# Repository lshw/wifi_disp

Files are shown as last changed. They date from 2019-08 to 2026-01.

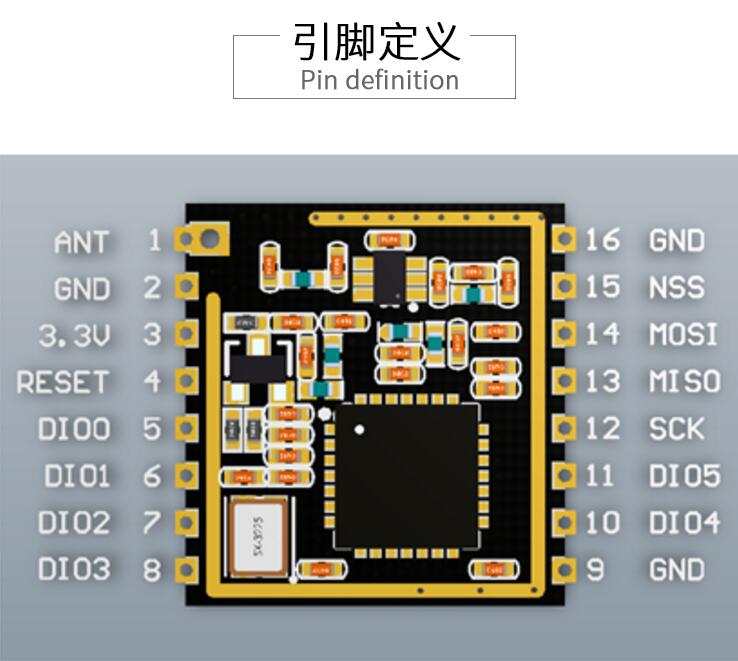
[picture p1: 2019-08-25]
doc/ra-01.jpg

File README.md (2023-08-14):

# wifi_disp
基于arduino开发环境，硬件使用esp8266做的一个智能硬件，可以arduino用串口更新程序，或者arduino用wifi ota方式更新程序

内带锂电池， 充满电， 可以工作40天

可以用wifi从web服务器获取5个数字，显示在数码管显示屏上，

带了个AP功能，让笔记本和手机可以接上来用内带的web服务器进行初始设置。

在连上外网后，还能进行自动远程http升级固件。  
本身带一个温度探头， 精度0.5度， 数据可以传到远程http服务器上进行存储。  
我现在用它给家里的室温和室外温度进行测试并记录，还用它作为美元汇率显示器。  
这个项目也可以作为esp8266开发的一个入门例子。  
源码在wifi_disp目录下。   
编译好的bin在 https://www.anheng.com.cn/wifi_disp.bin  

lib目录下的脚本，是linux下，不用arduino集成环境， 直接用命令行进行编译或者ota或者线刷的脚本

lora_mini是一个兼容arduino的uno，带lora功能的一个小板子，可以作为lora的探头端  

 V2版硬件,增加lora模块，cfido2019同款, 可以作为lora开发板学习研究lora， 也可以作为lora网关， 让lora网络覆盖一个住宅小区。  目前稳定测试通讯距离可以1.3公里  

这里是taobao链接， 提供全套散件，这个小小的套件， 可以体验学习如下诸多内容: 嵌入式开发，wifi开发, arduino,http开发，制作ap接入点，物联网应用，3D打印外壳，基于单片机dns泛域名解析， mdns发现，基于单片机的web服务器，好多内容， 适合于大中小学生玩耍,随便从以上各点取一个方向，做毕业设计是很好的。 

相关的项目链接:  
微信小程序[惠多气象]:https://github.com/scfido/weather_thermometer  
手机APP:https://github.com/liuxiaoyang98/wifi_disp_app  
 
淘宝连接:https://item.taobao.com/item.htm?id=601842691823  

看看能打到第几关:  

第一关，可以拿它当个温度计，可以Web看历史温度，~~小程序看温度~~

~~第二级，可以自动开通ddns.cfido.com,自己玩一些ddns的东西。~~

第三级，可以自己开发Web服务端，让它周期显示一些自己感兴趣的内容,5位数字,比如汇率等

第四级，扩展的TTL串口和I2C，可以自己扩展一些外设

第五级，进行lora无线通讯开发，使用arduino开发环境
模块支持3种通讯模式，2种传统的，和lora模式，频率433-470MHz（433,470是开放频率，可以进行智能家居，物联网等非连续通讯)

第六级，我们要建立开放的基于lora的，低功耗的,低速物联网通讯协议，用无中心的p2p网络实现互联。

编译方法：  
先安装arduino开发环境， 然后增加esp8266支持, 具体就是开发环境下点设置， 增加开发板管理器的url:https://arduino.esp8266.com/stable/package_esp8266com_index.json   
然后在开发板管理器里就可以搜到并安装esp8266的支持了，目前的源码需要选择3.0.2的esp8266支持环境  
在开发板里选Generic ESP8266 Modules 
Flash Size 选4M (fs:2M, 程序1M) 
MMU选16KB cache 48KB IRAM  
就可以编译了。

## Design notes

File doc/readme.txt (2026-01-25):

背后的按键可以切换运行模式
1.测温上传 -> 2.setup设置 -> off 关机

设置温度计wifi上网的方法:

如果wifi有wps快速配网功能，按一下无线AP的WPS键，
然后插上usb线，切换到setup模式,就会自动进行WPS配网，
如果WPS配网没有成功，进入smartconfig模式。 温度计显示 CO xx, 
此时手机连上家里2.4G的wifi网络， 用微信浏览网址
http://wx.ai-thinker.com/api/old/wifi/config
就可以给附近的温度计配置wifi上网密码。配置完成后，温度计会自动重启。
如果上述方法没有成功， 那么可以试试用温度计的AP服务，
在setup模式下, 温度计会生成一个空密码的名字叫disp的wifi接入点AP, 用手机或者笔记本可以搜到它
用手机(先关掉4G)或电脑，连上无线接入点disp后，用浏览器浏览网页http://192.168.4.1，
会打开web设置界面，把家里的WiFi和密码设置进去，然后保存重启。

远程显示温度方式:
温度历史数据地址1:https://temp2.wf163.com:1443/disp
温度历史数据地址2:https://temp.cfido.com/disp

Q&A:

Q:如何升级
A:web界面在线升级， 上传wifi_disp.bin, 或者用串口， 用update.sh在linux下进行升级，windows下需要安装python参考update.sh 用cmd命令行进行升级

Q:为啥会显示[ 3.xx ]或者[ 4.xx ]，并闪动?
A:这是温度计没有连上网络，它会显示电池电压, 需要给温度计配上wifi，让它上网。

Q:为啥温度计显示[OFF3.x]?
A:电池电压过低， 3.x是电池电压, 插上usb线充电就可以了。

Q:为啥显示温度会偏高?
A:在配置wifi时， 可能会因为温度计持续工作， 而造成温度升高， 等1小时后，它下次自动测量数据，就可以显示准确的气温，误差0.5度

Q:还有更详细的说明吗?
A:看源码网站:https:/github.com/lshw/wifi_disp

Q:怎么可以知道设备的序列号?
A:温度计上会有贴纸，写着序列号,如果找不到贴纸， 可以用以下方法， 找到序列号:
A:配好温度计的wifi设置后， 按背后的按键， 让它进入OTA模式, 等它完成上网， 就会在屏幕显示ip地址， 用手机或者电脑浏览这个ip地址，
   出来的设置页面上，可以显示温度计序列号

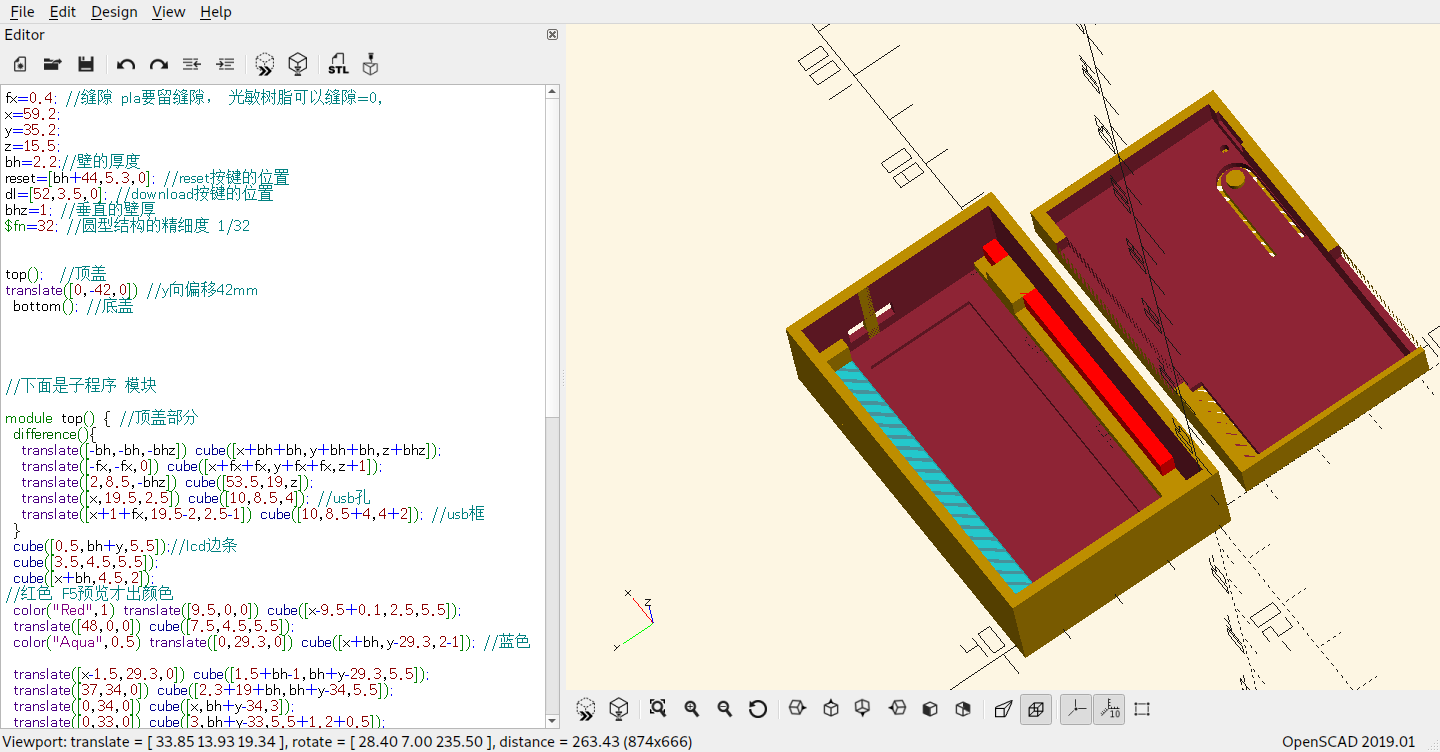
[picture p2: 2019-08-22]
doc/3d.png

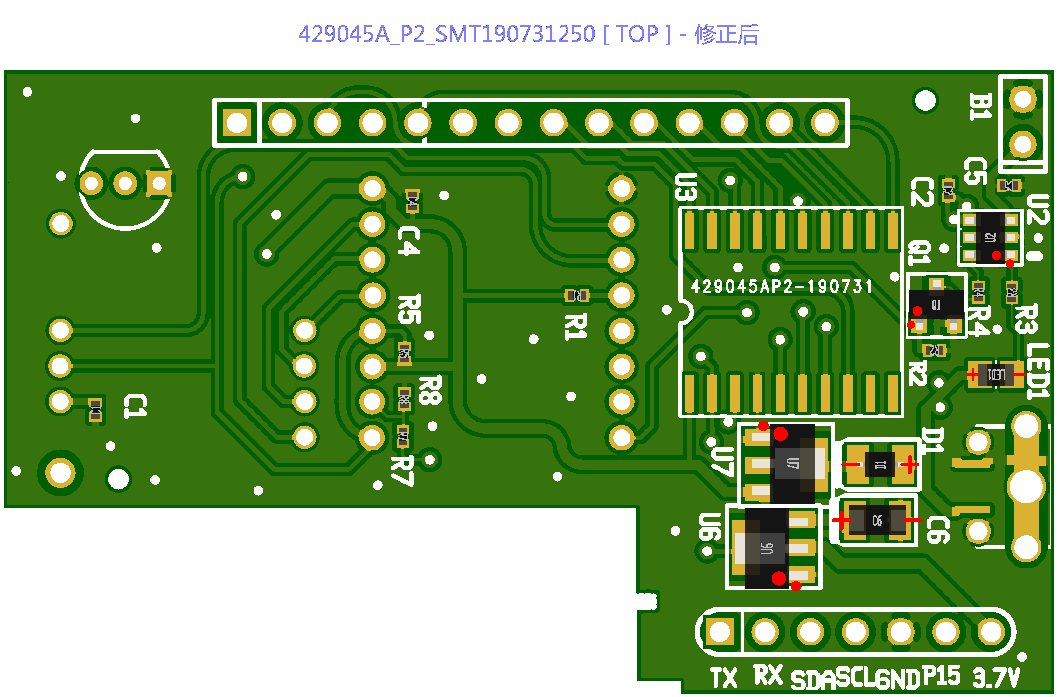
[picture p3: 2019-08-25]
doc/pcb_top.png

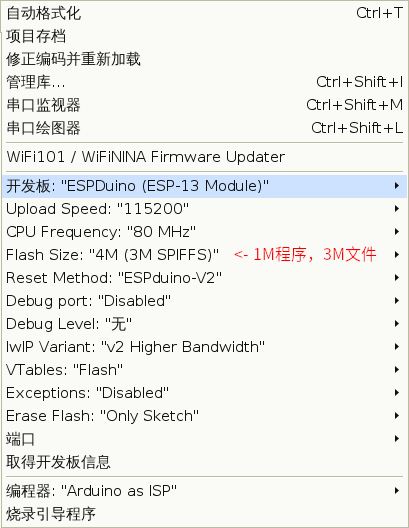
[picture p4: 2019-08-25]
doc/arduino_set.png

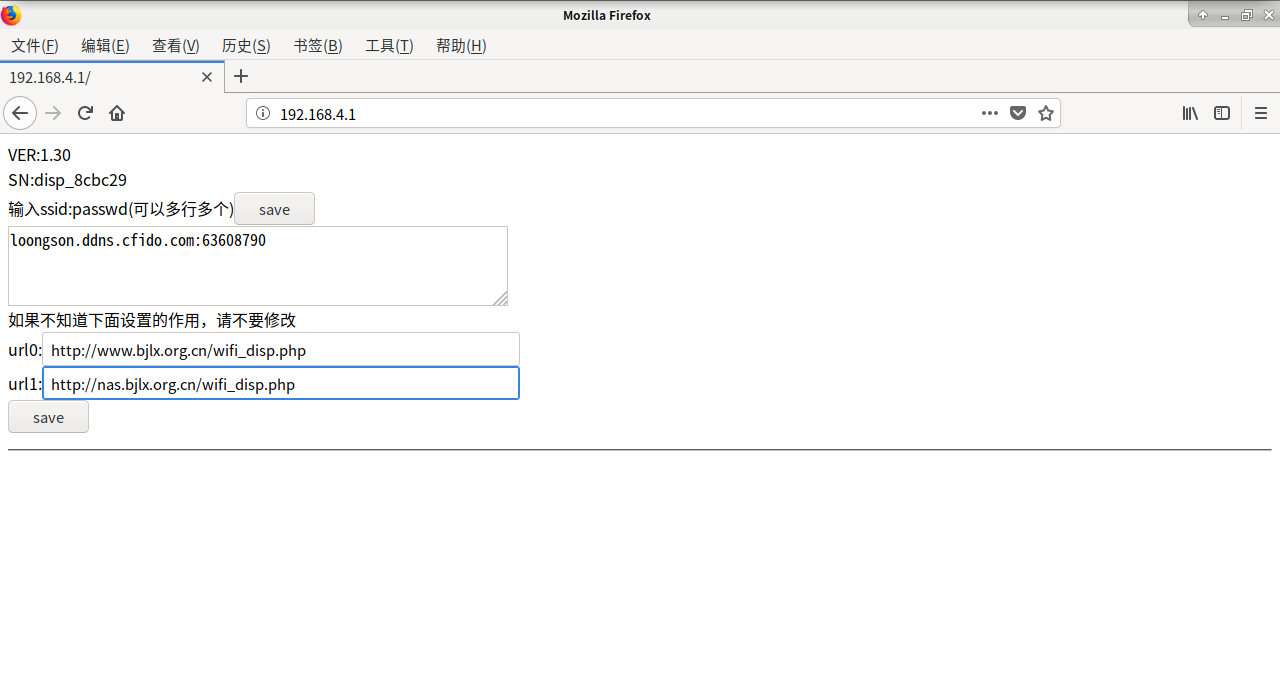
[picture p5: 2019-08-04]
doc/ap.png

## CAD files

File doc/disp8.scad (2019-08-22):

fx=0.4; //缝隙 pla要留缝隙， 光敏树脂可以缝隙=0,
x=59.2;
y=35.2;
z=15.5;
bh=2.2;//壁的厚度
reset=[bh+44,5.3,0]; //reset按键的位置
dl=[52,3.5,0]; //download按键的位置
bhz=1; //垂直的壁厚
$fn=32; //圆型结构的精细度 1/32


top();  //顶盖 
translate([0,-42,0]) //y向偏移42mm 
 bottom(); //底盖




//下面是子程序 模块

module top() { //顶盖部分 
 difference(){
  translate([-bh,-bh,-bhz]) cube([x+bh+bh,y+bh+bh,z+bhz]);
  translate([-fx,-fx,0]) cube([x+fx+fx,y+fx+fx,z]);
  translate([2,8.5,-bhz]) cube([53.5,19,z]);
  translate([x,19.5,2.5]) cube([10,8.5,4]); //usb孔
  translate([x+1+fx,19.5-2,2.5-1]) cube([10,8.5+4,4+2]); //usb框
 }
 cube([0.5,bh+y,5.5]);//lcd边条
 cube([3.5,4.5,5.5]);
 cube([x+bh,4.5,2]);
 translate([9.5,0,0]) cube([x-9.5+0.1,2.5,5.5]);
 translate([48,0,0]) cube([7.5,4.5,5.5]);
 translate([0,29.3,0])
 cube([x+bh,y-29.3,2-1]);

 translate([x-1.5,29.3,0]) cube([1.5+bh-1,bh+y-29.3,5.5]);
 translate([37,34,0]) cube([2.3+19+bh,bh+y-34,5.5]);
 translate([0,34,0]) cube([x,bh+y-34,3]);
 translate([0,33,0]) cube([3,bh+y-33,5.5+1.2+0.5]);
  translate([x+fx,19.5+8.5/2-1,0]) cube([1,2,z]); //usb支撑
}

module switch(){  //按钮开关结构
 fx1=0.8;
 bh=2;
 if(fx>0) { //fx>0 是pla打印，按键的缝隙要宽一点
  fx1=1.6;
 }
 r1=4.8+fx1+fx1;
 difference(){
  union(){
   cylinder(r=r1/2,h=bh);
   translate([-15,-r1/2,0]) cube([15,r1,bh]);
  }//union
  cylinder(r=r1/2-fx1,h=bh);
  translate([-15,-r1/2+fx1,0]) cube([15,r1-fx1-fx1,bh]);
 }//diff
}

module bottom(){ //底盖部分
 z1=5+1.5; //厚度
 bh=2;      //壁厚
 difference(){
  cube([x,y,z1]);
  translate([1,bh,1.5]) cube([x-1-1.6,y-bh-bh,z1]);
  translate([2,30,0]) cube([18,3.1,z1]); //com1
  translate([1,0,z1-3.7]) cube([23,bh,z1]);//电池
  translate([1+18,y-bh,1.5+2]) cube([33,bh,z1]);//天线
  translate(dl) {
   cylinder(r=0.7,h=bh);
   translate([-7/2,-4/2,z1-3]) cube([7,4,z1]); //3x6 开关
  }
  translate(reset) switch();
 }
 translate(reset) cylinder(r=3/2,h=z1-4.2);//按键中心柱
}

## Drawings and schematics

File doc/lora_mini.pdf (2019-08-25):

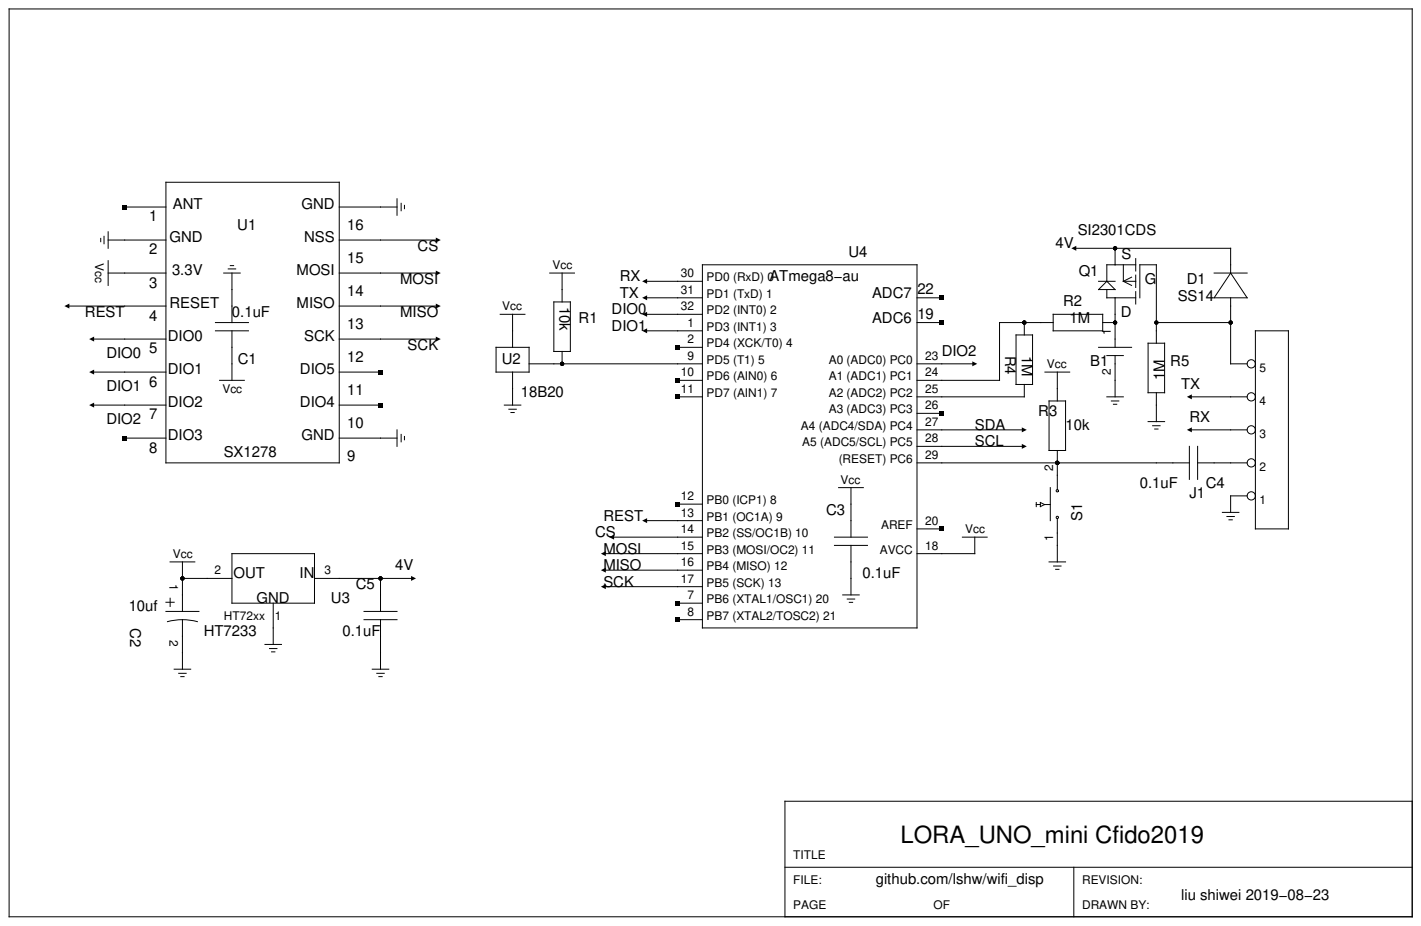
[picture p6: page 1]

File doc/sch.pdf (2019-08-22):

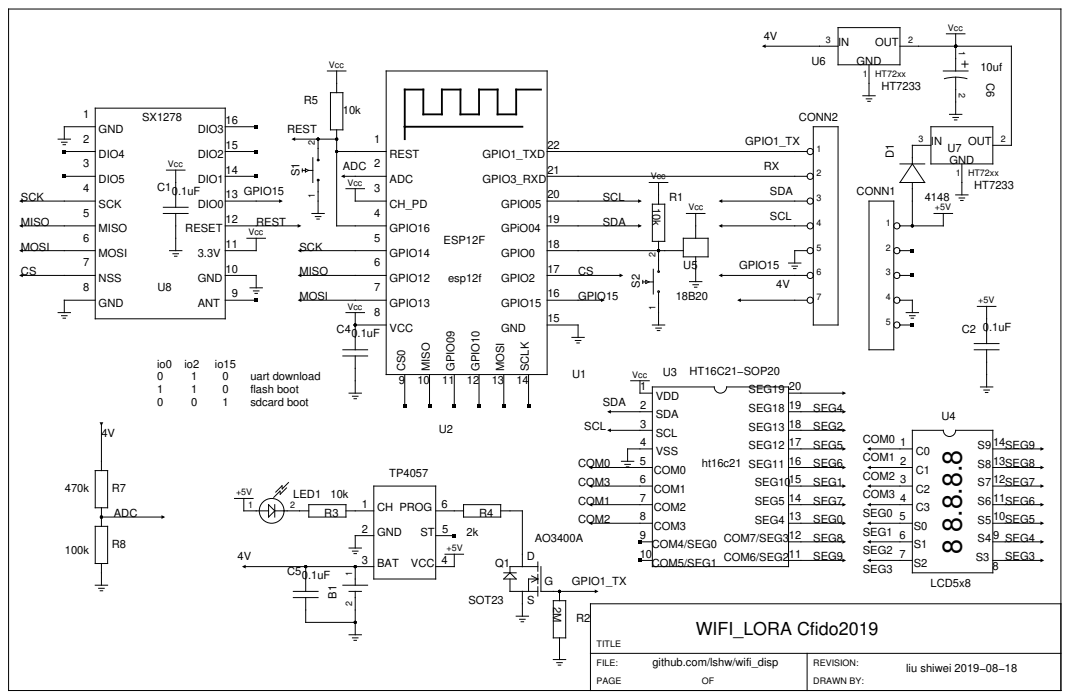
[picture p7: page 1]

liu shiwei 2019−08−18 github.com/lshw/wifi_disp

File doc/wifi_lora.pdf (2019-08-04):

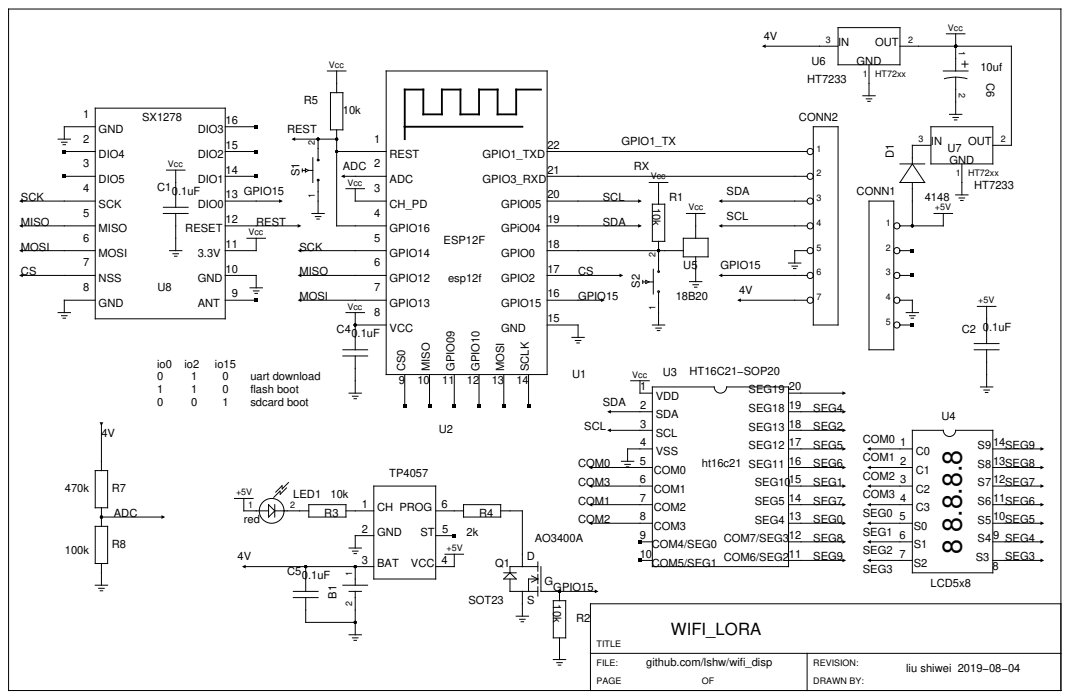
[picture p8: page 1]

liu shiwei 2019−08−04 github.com/lshw/wifi_disp

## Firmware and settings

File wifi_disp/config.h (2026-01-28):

#ifndef _CONFIG_H_
#define _CONFIG_H_

#define VER "1.86"
#define HOSTNAME "disp_"
#define CRC_MAGIC 3
/* ESP32_C3 MAGIC 4 */
#define DEFAULT_URL0 "http://temp.cfido.com:808/wifi_disp.php"
#define DEFAULT_URL1 "http://temp2.wf163.com:808/wifi_disp.php"

#ifndef GIT_VER
#define GIT_VER "test"
#endif
#define DOWNLOAD_KEY 0
#ifndef BUILD_SET
#define BUILD_SET "default"
#endif

#endif  //_CONFIG_H_

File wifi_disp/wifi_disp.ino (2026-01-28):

#include <FS.h>
#ifndef CONFIG_IDF_TARGET_ESP32C3
extern "C" {
#include "user_interface.h"
}
#endif
#include "config.h"
#include "global.h"
void ht16c21_cmd(uint8_t cmd, uint8_t dat);
void init1();
uint32_t next_disp = 1800;  //下次开机
String hostname = HOSTNAME;

#include "ota.h"
#include "ds1820.h"
#include "wifi_client.h"
#include "httpd.h"
#include "ht16c21.h"
#include "lora.h"
#include "dht22.h"
#include "sht4x.h"
#include "setup.h"
#include "proc3.h"
#if __has_include("proc4.h")
#include "proc4.h"
#endif
#if __has_include("proc5.h")
#include "proc5.h"
#endif
bool power_in = false;
void init1() {
  ht16c21_setup();       //180ms
  ht16c21_cmd(0x88, 1);  //闪烁2hz
}
void setup() {
  Serial_begin();
  load_nvram();  //从esp8266的nvram载入数据
  nvram.boot_count++;
  nvram.change = 1;
  if (millis() > 5000) {  //升级程序后第一次启动
    Serial.println(F("升级完成，重启"));
    nvram.charge = 1;
    nvram.change = 1;
    save_nvram();
    poweroff(2);
  }
  //WiFi.setAutoConnect(true);                        //自动链接上次
  if (nvram.have_dht == 0 && nvram.pcb_ver >= 0) {  //dht与wifi_station_connect冲突
    if (nvram.proc == PROC3_MODE || nvram.proc == GENERAL_MODE) {
      wifi_set_opmode(STATION_MODE);
      wifi_set_sleep_type(NONE_SLEEP_T);
      if (!ip_addr_isany(&nvram.ip.ip) && !ip_addr_isany(&nvram.ip.gw) && !ip_addr_isany(&nvram.ip.netmask)) {
        wifi_station_dhcpc_stop();
        wifi_set_ip_info(STATION_IF, &nvram.ip);
        dns_setserver(0, &nvram.dns0);
        dns_setserver(1, &nvram.dns1);
      }
      struct station_config conf = { 0 };
      wifi_station_get_config(&conf);
      conf.channel = nvram.ch;
      wifi_station_set_config_current(&conf);
      wifi_station_connect();
    } else if (nvram.proc == SETUP_MODE) {
      wifi_set_opmode(STATIONAP_MODE);
      wifi_station_connect();
    }
  } else {
    pcb_ver_detect();
  }
  if (nvram.ds18b20_pin >= 0)
    ds_init();
  get_batt();
  check_batt_low();
  add_limit_millis();
  proc = nvram.proc;    //保存当前模式
  switch_proc_begin();  //开始时切换
  switch (proc) {       //尽快进行模式切换
#if __has_include("proc5.h")
    case PROC5_MODE:
      proc5_setup();
      break;
#endif
#if __has_include("proc4.h")
    case PROC4_MODE:  //lora发送测量值模式, 插电做网关， 不插电做远端.
      proc4_setup();
      break;
#endif
    case PROC2_MODE:
      nvram.change = 1;
      save_nvram();
      init1();
      disp(F(" P2 "));
      delay(100);
      delay_more();  //外插电，就多延迟，方便切换
      if (bmp.begin()) {
        if (nvram.have_bmp != 5) {
          nvram.have_bmp = 5;
          nvram.change = 1;
          save_nvram();
        }
        snprintf_P(disp_buf, sizeof(disp_buf), PSTR("%f"), bmp.readAltitude());
        disp(disp_buf);
        shan();
        poweroff(60);
        return;
      } else {
        if (nvram.have_bmp > -5)
          nvram.have_bmp--;
        else {
          nvram.proc = GENERAL_MODE;
          proc = nvram.proc;
        }
        nvram.change = 1;
        save_nvram();
        poweroff(2);
      }
      break;
    case PROC3_MODE:
      init1();
      disp(F(" P3 "));
      proc3_setup();
      break;
    case SETUP_MODE:
      set_hostname();
      hello();
      setup_setup();
      nvram.pcb_ver = -1;
      pcb_ver_detect();
      break;
    case OFF_MODE:
      init1();
      set_hostname();
      hello();
      disp(F(" OFF "));
      delay(2000);
      disp(F("-" VER "-"));
      delay(2000);
      ht16c21_cmd(0x84, 0x02);  //关闭ht16c21
      if (nvram.pcb_ver > 0) {  //v2.0
        if (nvram.have_lora > -5 & lora_init())
          lora.sleep();
        Serial_begin();
      }
      if (nvram.have_lora < 0) {
        nvram.have_lora = 0;
        nvram.change = 1;
      }
      if (!ip_addr_isany(&nvram.ip.ip)) {
        memset(&nvram.ip.ip, 0, sizeof(nvram.ip.ip));
        nvram.change = 1;
      }
      save_nvram();
      poweroff(0);
      return;
      break;
    case LORA_SEND_MODE:
      Serial.println(F("lora  发送模式"));
      if (lora_init()) {
        init1();
        disp(F("S-" VER));
        wifi_station_disconnect();
        wifi_set_opmode(NULL_MODE);
        WiFi.mode(WIFI_OFF);
        delay(1000);
        return;
      }
      poweroff(10);
    case LORA_RECEIVE_MODE:
      Serial.println(F("lora  接收模式"));
      init1();
      disp(F("L-" VER));
      if (lora_init()) {
        disp(F("L-" VER));
        wifi_station_disconnect();
        wifi_set_opmode(NULL_MODE);
        WiFi.mode(WIFI_OFF);
        delay(1000);
        return;
      }
      poweroff(10);
    case GENERAL_MODE:
    default:
      proc = GENERAL_MODE;  //让后面2个lora在不存在的时候，修正为proc=0
      init1();
      snprintf_P(disp_buf, sizeof(disp_buf), PSTR("-%3.2f-"), v);
      disp(disp_buf);
      pcb_ver_detect();
      if (nvram.have_dht == 1 && wendu < -299.0)
        dht_();  //dht必须在wifi打开之前
      wifi_set_opmode(STATION_MODE);
      wifi_station_connect();
      set_hostname();
      hello();
      _myTicker.attach(1, timer1s);
      Serial.println(F("测温模式"));
      if (nvram.have_dht == 0)
        get_value();
      if (wendu == 85.00 && nvram.ds18b20_pin >= 0) {
        for (uint8_t i = 0; i < 10; i++) {
          if (get_temp()) {
            Serial.printf_P(PSTR("get_temp() %d\r\n"), i);
            break;
          }
          yield();
          delay(100);
        }
      }
      delay_more();  //外插电，就多延迟，方便切换
      WiFi_isConnected();
      if (nvram.pcb_ver > 0 && nvram.have_lora > -5) {
        if (lora_init())
          lora.sleep();
      }
      Serial.println();
      wait_connected(5000);
      shan();
      wait_connected(30000);
      Serial.println();
      if (WiFi_isConnected()) {
        wput();
      } else {  //30秒没有连上AP
        if (power_in) {
          wifi_config();
          return;
        }
        //10秒超时1小时重试。
        Serial.print(millis());
        Serial.println(F("ms,not link to ap,reboot 3600s"));
        ht16c21_cmd(0x88, 3);  //慢闪烁
        poweroff(3600);
      }
      break;
  }
}

void wput() {
  uint16_t httpCode = wget();
  if (httpCode >= 200 && httpCode < 400) {
    ip_info now_ip;
    ip_addr_t dns0, dns1;
    dns0 = *dns_getserver(0);
    dns1 = *dns_getserver(1);
    wifi_get_ip_info(STATION_IF, &now_ip);
    if (!ip_addr_cmp(&now_ip.ip, &nvram.ip.ip)
        || !ip_addr_cmp(&now_ip.netmask, &nvram.ip.netmask)
        || !ip_addr_cmp(&now_ip.gw, &nvram.ip.gw)
        || !ip_addr_cmp(&dns0, &nvram.dns0)
        || set0.dns_ip_change == 1
        || !ip_addr_cmp(&dns1, &nvram.dns1)) {
      wifi_get_ip_info(STATION_IF, &nvram.ip);
      nvram.dns0 = *dns_getserver(0);
      nvram.dns1 = *dns_getserver(1);
      nvram.change = 1;
      Serial.println(F("保存当前net信息"));
    }
    if (nvram.ch != wifi_get_channel()) {
      nvram.ch = wifi_get_channel();
      nvram.change = 1;
    }
    Serial.print(F("uptime="));
    Serial.print(millis());
    if (next_disp < 60) next_disp = 1800;
    Serial.print(F("ms,sleep="));
    Serial.println(next_disp);
    if (millis() < 500) delay(500 - millis());
    poweroff(next_disp);
  } else {
    Serial.print(millis());
    Serial.println(F("删除上次net信息"));
    Serial.println(F("ms,web error,reboot 3600s"));
    memset(&nvram.ip.ip, 0, sizeof(nvram.ip.ip));
    nvram.change = 1;
    ht16c21_cmd(0x88, 3);  //慢闪烁
    poweroff(3600);
  }
}

void loop() {
  system_soft_wdt_feed();
  if (power_off) {
    yield();
    delay(1000);
    return;
  }
  if (run_millis_limit < millis()) {
    Serial.print(F("超时关机，millis()="));
    Serial.println(millis());
    poweroff(3600);
  }
  switch (proc) {
    case SETUP_MODE:
      setup_loop();
      break;
    case PROC4_MODE:
      if (nvram.pcb_ver > 0 && nvram.have_lora > -5) {
        add_limit_millis();
        if (lora_init()) {
          lora_receive_proc4();
          if (rxLen > 0 && send_limit < 80) {
            rxLen = 0;
            rxBuf[0] = 0;
            send_limit += 20;  //猝发4次后每20秒发送一次
          }
        } else delay(200);
        break;
      }
    case LORA_RECEIVE_MODE:
      if (nvram.pcb_ver > 0 && nvram.have_lora > -5) {
        add_limit_millis();
        if (lora_init())
          lora_receive_loop();
        else delay(200);
        break;
      }
    case LORA_SEND_MODE:
      if (nvram.pcb_ver > 0 && nvram.have_lora > -5) {
        add_limit_millis();
        if (lora_init())
          lora_send_loop();
        delay(400);
        break;
      }
  }

  if (setup_mode == SMARTCONFIG_MODE) {
    if (WiFi.smartConfigDone()) {
      yield();
      save_ssid();
      setup_mode = NONE_MODE;
      WiFi.stopSmartConfig();
    }
    setup_loop();
  }
  if (nvram.change) save_nvram();
  get_batt();
  yield();
  if (proc == SETUP_MODE && nvram.pcb_ver == 1) {
    Serial_end();
    charge_on();
    delay(350);
    charge_off();
    Serial_begin();
  } else
    delay(350);
  yield();
}

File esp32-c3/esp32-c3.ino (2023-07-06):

bool power_in = true;
#define uS_TO_S_FACTOR 1000000ULL
#include "ht16c21.h"
RTC_DATA_ATTR uint16_t count;

  char disp_buf[15];
void setup() {
  ht16c21_setup();
  pinMode(3,OUTPUT);
  digitalWrite(3,HIGH);
  Serial.begin(115200);
  count++;
  snprintf(disp_buf, sizeof(disp_buf), "%05d", count);
  disp(disp_buf);
  Serial.println(disp_buf);
  Serial.print("ibat:");
  Serial.println(get_batt(2));
  Serial.print("ebat:");
  Serial.println(get_batt(1));
  Serial.flush();
  delay(1000);
  esp_sleep_enable_timer_wakeup(2 * uS_TO_S_FACTOR);
  esp_deep_sleep_start();
}
void loop() {
}

float get_batt(uint8_t adc) {//锂电池电压
  uint32_t dat = analogRead(adc);
  dat = analogRead(adc)
        + analogRead(adc)
        + analogRead(adc)
        + analogRead(adc)
        + analogRead(adc)
        + analogRead(adc)
        + analogRead(adc)
        + analogRead(adc);

    return (float) dat / 8 * (470.0 + 100.0) / 100.0 / 1023 /5.33*3.87;
}

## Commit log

2018-12-05 wifi_ota完成， http_update 通过web服务器update完成， 把各功能放到不同的.h文件中： ap_web.h ap接入点，web服务器，dns服务器，建立ssid:disp的ap， 等待手机或电脑连上来进行设置更新 ds1820.h 测温 ht16c21.h lcd显示， lcd ram管理 http_update.h 通过web升级固件 wifi_client.h 作为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
2018-12-05 增加字符O,t
2018-12-05 电压低于3.6V开始闪动
2018-12-05 整理电池电压以及充电控制部分
2018-12-05 H字符会被显示未O, 3D打印外壳
2018-12-05 ota时显示ip地址
2018-12-05 http_update成功后， 显示HUP O, lcd 走马灯的小数点，继续修改
2018-12-05 进入AP模式时，强制充电
2018-12-05 电源接入检测
2018-12-05 ota / ap模式，关闭看门狗
2018-12-05 web服务器下发 'UPDATE'，会进入 http 升级
2018-12-05 ota ip显示顺畅，不在跳动
2018-12-05 修改外壳
2018-12-05 ota loop循环需要喂狗watch dog
2018-12-05 修复温度85.00
2018-12-05 取消手动http update 防止升级过程手误造成固件损坏,poweroff(-1)是永久关闭，增加关机模式
2018-12-05 增加信号强度
2018-12-05 修复充电时不上传温度的问题 修改充电终止电压
2018-12-05 优化测温代码，v1.12
2018-12-07 测温更可靠
2018-12-09 调整电压测量，充电控制
2018-12-09 电压太低，不做http_update
2018-12-09 增加设置url，将用于自定义服务器地址
2018-12-09 使用url设置值， 代替原来程序中写死的服务器url
2018-12-09 在ota模式下,用浏览器浏览ip,可以进行web设置，
2018-12-09 版本1.15
2018-12-09 修复充电不满就停的问题
2018-12-09 每次http_update后， 都开启充电 v1.18
2018-12-09 如果插了外接电源，但不需要充电，可以直接关机
2018-12-14 lcd的RAM作为不掉电RAM来用，初始化时， 要尽早读入，否则会被清零,造成不能用reset切换运行模式 V1.20
2018-12-14 在set页面，显示SN
2018-12-14 在OTA时，屏幕显示进度
2018-12-28 自动修正中文的冒号间隔
2019-01-06 调整出问题时候的关机时间，防止网络或服务器出问题造成过渡电量消耗
2019-01-22 整理lcd代码
2019-01-22 可以有多个温度探头
2019-01-22 可以有2个url进行上传数据
2019-01-22 增加BSSID显示
2019-01-22 让18b20可以只用2根引脚，就可以工作.
2019-01-23 web服务， 可以浏览spiffs上的文本文件比如 /ssid.txt /wifi_set.txt /url.txt /url1.txt
2019-01-23 保存成功的wifi设置(ssid,passwd,频道，ip，子网掩码，网关，dns)到 /wifi_set.txt,下次通讯时，先用这些设置进行通讯，跳过dhcp等过程，应该会比较快
2019-01-23 保存成功的url,下次先用上次成功的url，不行再用另一个url试试
2019-01-23 开机时，先不打开wifi, v1.27
2019-01-24 1.28 update 时用当前的服务器地址， 而不是一致用url0
2019-01-30 如果上次wifi_set.txt 通讯有问题，就删除它，并重新联网
2019-01-30 说明更新
2019-07-04 自动诊断 ds在哪个腿 12 or 0
2019-07-04 自动判断板子类型 ds_pin=12 老型号， ds_pin=0 新型号带lora
2019-07-22 缺少的文件
2019-07-22 缺省url放到独立一个文件里 增加字符:'L'
2019-07-22 ota时，接收完成，刷机过程时闪动，刷机完成停止闪动
2019-08-04 测试输出上次的通讯参数
2019-08-04 修正ping代码
2019-08-04 清上次通讯成功的ssid变量
2019-08-04 http请求2秒超时
2019-08-04 开机清console窗口
2019-08-04 ap设置的图片
2019-08-04 lora spi test
2019-08-04 引入 https://github.com/846354866/LoRa LoRa库
2019-08-16 外壳设计 3D打印外壳
    [disp8.scad]
2019-08-16 V2.0硬件，电池测量分压电阻是470k/100k
2019-08-17 默认的ssid:test,密码:cfido.com 电压是浮点数据
2019-08-17 程序排版
2019-08-17 V2.0硬件，复用充电控制腿。。。
2019-08-22 左下角的点，表示外插电
2019-08-22 暂时关闭 ping 升级到 esp8266 arduino 2.5.2
    编译脚本升级
2019-08-22 电路图
    安装arduino环境的脚本
    [disp8.scad]
2019-08-22 3D外壳，以及openSCAD软件截图
    [disp8.scad]
2019-08-25 说明和图片
2019-08-25 lora_mini 板的电路图,超低功耗 cr2032运行2年,门磁，测温，开关,定位
2019-09-17 lora速率降为7.8k
2019-09-17 web超时，设置为4秒
2019-09-18 OTA时， 不用上次的成功设置，而是重新连接wifi
2019-09-18 增加lora_mini 电路图 测试程序
    [lora_mini.sch]
2019-09-18 调整代码缩进, 在lora发送和接收时，先显示一下版本号， 在接收时， 显示 信号强度 RSSI
2019-09-18 RSSI换算成 -dBm V1.34
2019-09-19 将信号带宽放到250Kbps 这样可以做到大约200bps的速率。。。 修改频率为434.5Mhz
2019-09-19 代码缩进 V1.35
2019-09-19 434.5Mhz 把LoRa库， 嵌入到源代码中 lora_mini用TX中断方式
2019-09-21 loro_mini 一个数组溢出bug
2019-09-24 配置 vscode编译环境
2019-09-26 增加 微信客户端和app客户端的项目链接
2019-12-02 新版lora_mini板
2019-12-08 整合非lora版本到主线
2019-12-09 电压过低时， off1 充电半小时
2020-02-07 修复nexttime超过6小时就一直重复通讯，电量耗尽的bug
2020-02-07 0秒不显示
2020-02-07 修改升级时候的 http超时为40秒
2020-02-08 关机时增加软件版本显示 V1.40
2020-02-08 需要充电时，亮左下角的三角，有外接电源时亮左上的三角
2020-02-08 修复温度计不能充电问题
2020-02-08 off时如果闪动时按复位是进lora测试，如果是自行关闭，就进程序0
2020-02-08 python写的wifi ota升级程序
2020-02-08 V1.42 bin文件
2020-03-16 服务器端的例子，用于获取国内武汉肺炎确诊总数
2020-04-12 update脚本升级
2020-04-14 替换www.cfido.com 为temp.cfido.com:808, www.cfido.com在国外，有时候很慢甚至不通 url可以带参数 清理无效的功能 V1.43
2020-04-14 修改php服务器例子, wifi_disp.bin v1.43
2020-04-14 把文件末尾增加4个字节，用于碰撞出任意的crc32
2020-04-14 ap模式也可以进行web升级和ota升级
2020-04-14 增加web上传升级firmware功能
2020-04-14 合并AP_MODE和OTA_MODE
2020-04-14 插电的情况下,进入设置状态,最长半小时
2020-04-14 off状态下， 4秒以内按键可以切换到下一个程序，如果等它自动关机了，再按键，就是进入程序1:测温上传
2020-04-15 清理代码， 去掉重复的http_listen()
2020-04-16 替换网址，清理老的服务器地址 bin文件 V1.46
2020-04-16 fix ssid配置丢失的问题 v1.47 wifi_disp.bin
    [wifi_client.h, wifi_disp.ino]
2020-04-16 整理代码
2020-04-16 wifi模式不在ota_loop中执行
2020-04-16 OTA方式开AP，其它的只开client
2020-04-16 连不上wifi ，最多重试20秒
2020-04-16 减少loop中喂狗次数
2020-04-17 提升性能，提高反应速度 V1.48
2020-04-17 http.setTimeout函数在没有初始化时执行，会随机出错
2020-04-17 http下载升级增加进度显示
2020-04-17 V1.50 合并http_update.h 到 wifi_client.h函数
2020-04-19 代码整理
2020-04-19 如果开机电压低于3.5V,显示[OFF电压]
2020-04-19 增加湿度探头DHTxx V1.51
2020-04-19 没有湿度探头时，不做湿度上传
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2020-05-16 扫描并列出周围的ssid 点击扫描到的ssid 输入密码进行保存 显示当前链接的wifi 显示温度 保存设置不再重启
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2020-05-26 换名 server -> httpd
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2021-12-14 lora和dht 都用自动侦测的方式， 来判断有无， 侦测五次， 没有的话， 以后就不再侦测， 进入ota后， 复位侦测次数，从新开始侦测， 不再使用宏定义来控制lora和dht外设的有无
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2021-12-15 V1.59 ota的web界面增加 reboot按钮
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2021-12-16 在OTA模式， 10秒内， 侧重于链接上游AP, 10秒后， 工作重点转移到让下游客户端连上来
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2021-12-16 解决AP模式下， 首页打不开的问题,
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2021-12-17 增加一个函数， 把一行 ssid:password 放入/ssid.txt
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2021-12-17 插上电， 等20秒， 如果没有上网成功， 就会进入 CO xx计数， 100秒之内完成下面的操作
    手机连上2.4G的wifi,然后微信打开网页：http://wx.ai-thinker.com/api/old/wifi/config 开始配置
2021-12-17 ota 开机， 先1秒钟等待wifi上线，然后WPS自动配置网络 一次(20秒),然后进入AP(200秒/1000秒)
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2022-11-21 解决在没有lora模块时， 程序崩溃问题
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2022-11-28 修复lora库, 解决lora容易崩溃问题
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2022-11-28 V1.68 gcc重复define编译警告问题
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2023-06-26 修复web下发命令 : WIFI_SET_ADD=test:cfido.com 增加命令 OFF
    [wifi_client.h]
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2023-07-02 服务器程序修改， 5位数字， 同时显示温湿度的话， 只能显示到整数位
    增加不同sn号对应不同的显示内容
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2023-07-10 修复服务器端程序的api函数，cache功能
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2023-07-13 使用Adafruit BMP085 Library 库，测气压和海拔
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2023-08-14 更换目标板型号， 从espduino 到 一般类型的esp8266， 打开debug信息输出
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2023-08-14 切换方式改为 P1 -> P2 -> P3(usb) ->SETUP -> OFF -> lora_recv -> lora_send ->P1
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2023-08-14 整理显示屏的闪动， 可以切换时 2hz, 电压低于3.55V是1hz,
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2023-08-14 V1.75 修复新的不用18C20测温的硬件，在proc3下，测温异常的问题
2023-08-14 pcb ver 1 修复串口信息输出， 因为pcb1的充电控制跟串口Tx腿是同一个
    [global.h, wifi_disp.ino]
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2023-08-21 setup 程序， 没有dht的情况， 可以尽快开wifi
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2023-08-22 解决AP模式能ping192.168.4.1 但是不能打开http://192.168.4.1的问题
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2023-09-13 fix气压发送
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2023-09-16 增加程序5, 用来扫描并记录周围的ssid/mac， 然后可以在另一个地方回放， 用来mac定位地点仿真
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2024-10-09 proc3_host = NULL时， 关闭P3
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2024-10-09 fix 点击wifi名字添加wifi
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2026-01-23 开机时， 把上次的wifi设置，从flash 复制到 ram
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2026-01-24 httpCode修复
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2026-01-24 fix webcmd长度
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2026-01-27 1.84->1.85 nvram.url[32]长度不够, 并尝试自动修复
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2026-01-28 修复设置的url不起作用的bug, 取消NVRAM7_URL的url选择标志，使用nvram.url_no长度1bit的数作为标志
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2026-01-28 整理升级后url的恢复， 有/url.txt, 就载入，没有就用default V1.86
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
